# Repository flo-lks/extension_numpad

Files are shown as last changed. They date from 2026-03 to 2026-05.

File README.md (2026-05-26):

# Extension Numpad
4x4 numpad to connect to your PC if you don't have one. The rotary encoder can be used to control the PC volume.
Future additions could include a way to switch between different keymaps to use it as a real macro pad.

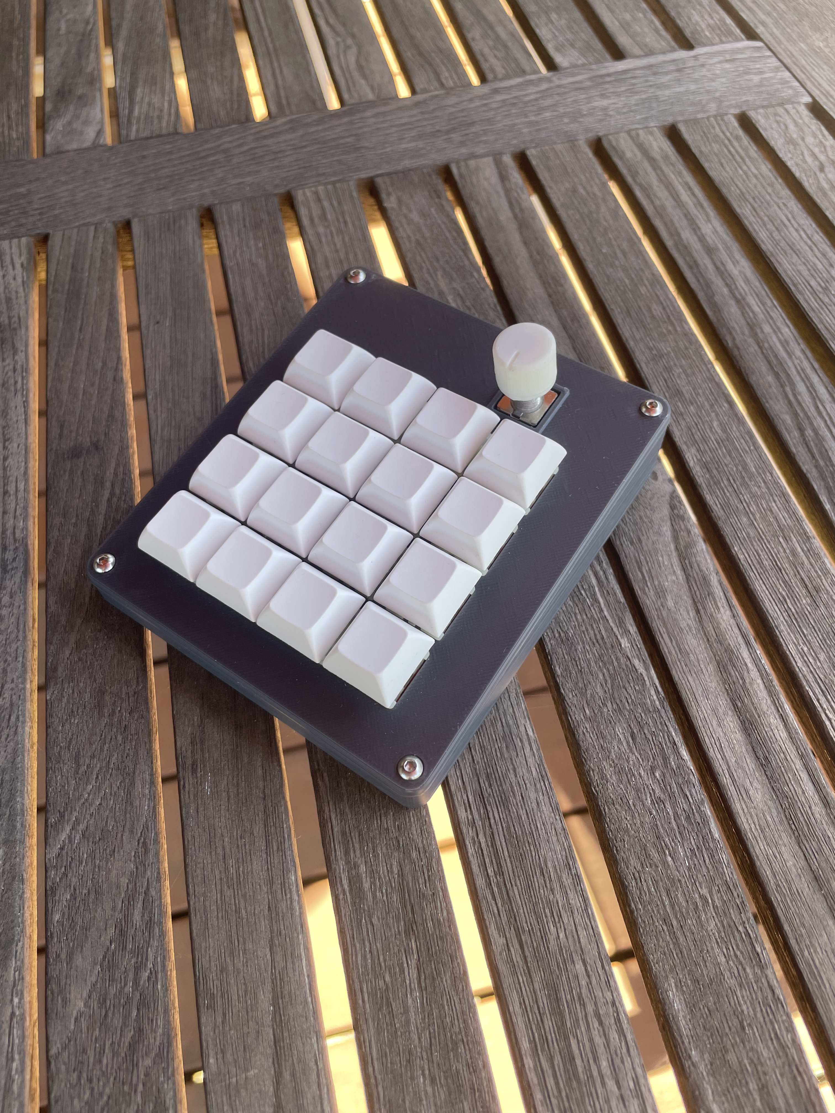
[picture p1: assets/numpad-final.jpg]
final picture of numpad


[demo](https://youtu.be/KasFj6y4_b8)

## PCB
### Schematic
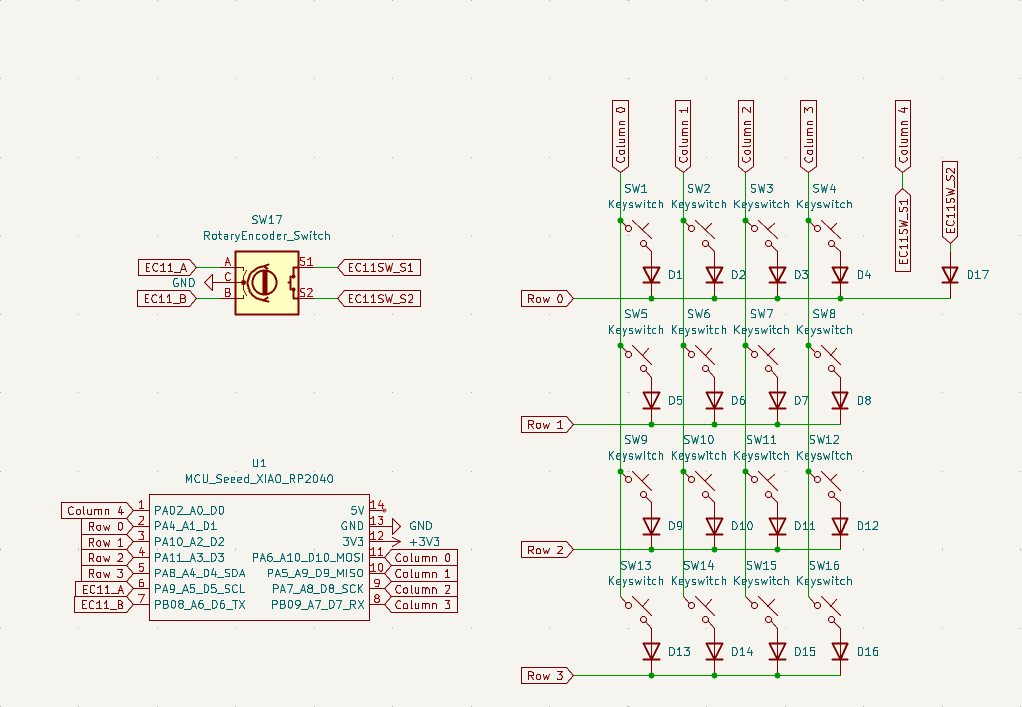
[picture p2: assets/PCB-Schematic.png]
PCB Schematic


### PCB Layout
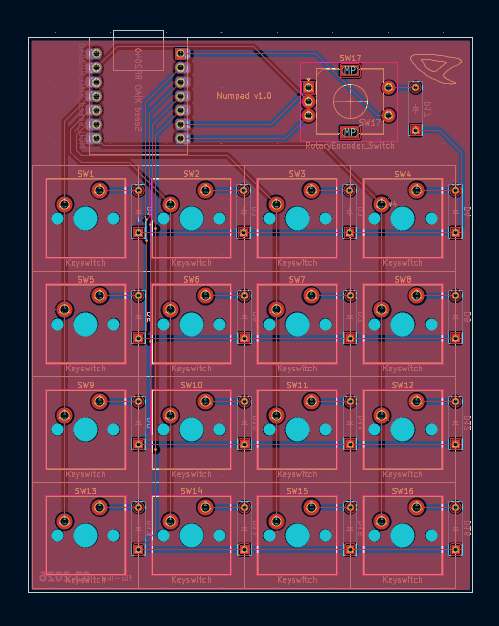
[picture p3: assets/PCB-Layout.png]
PCB Layout


### PCB 3D Model
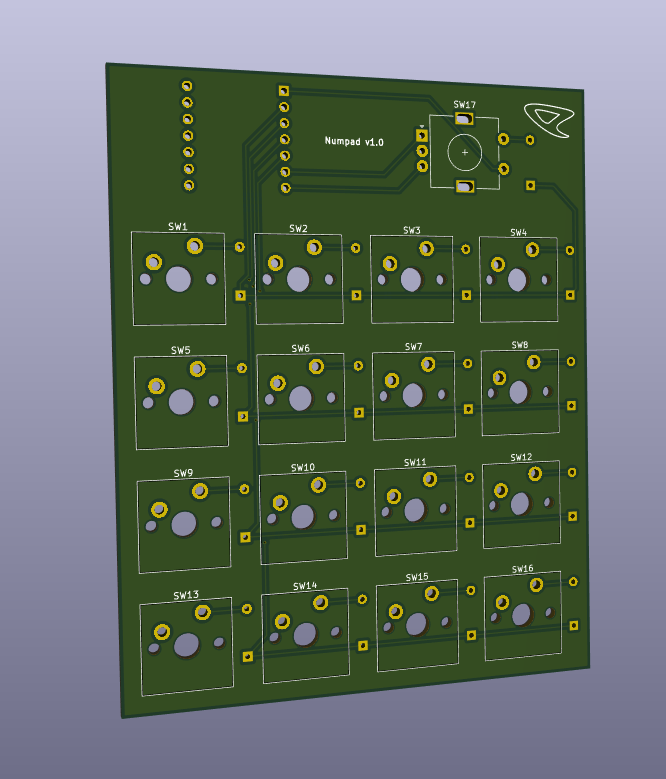
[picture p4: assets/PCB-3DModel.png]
PCB 3D model


## Case
I use a sandwich-mount case design, which consists of a base and a top part. It is angled at 7 degrees for a more comfortable typing experience. The switches clip into the top plate, which is screwed to the base with the help of the heatset inserts.
Here are the OnShape Links to all parts: [Base](https://cad.onshape.com/documents/cdbf6aaf84bb518f5fc41afd/w/d72aa09dfed84ea584997cdd/e/9ded30b820c111a83a06e4c5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), [Top](https://cad.onshape.com/documents/c205197f0eaaebc37cb0e7a9/w/398f6db9231d82ebe460adb4/e/7adaa80a929649ca5ef38242), [Rotarydial](https://cad.onshape.com/documents/0cc47eeeedf213fb4d3bd97f/w/859b01936aa7040036e683de/e/ecc9304a4732aee6efb41bf1), [Assembled](https://cad.onshape.com/documents/a27341ff84a250cd76250f05/w/721d63d8f915e883e9c7e543/e/c5b1b98a970bf75277e2f763)

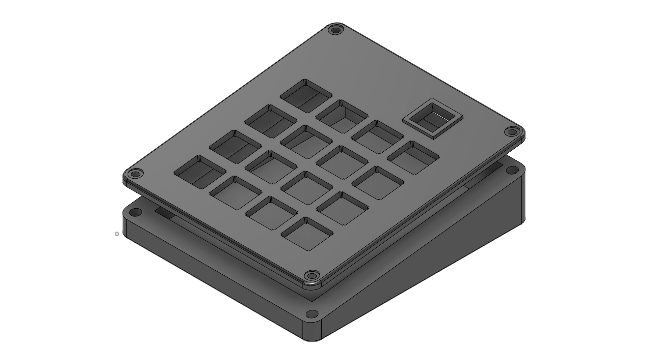
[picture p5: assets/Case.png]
Render of the case


## Firmware
This numpad uses the [QMK](https://qmk.fm/) firmware, with a basic numpad layout.

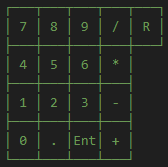
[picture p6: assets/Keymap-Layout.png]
Keymap-Layout


## BOM
| Qty | Part |
|-----|---|
| 1 | 3D Printed Case (1x Base, 1x Top) |
| 1 | EC11 (Switch) Rotary Encoder |
| 1 | PCB |
| 1 | Rotary Encoder Knob |
| 1 | Seeed Studio XIAO RP2040 |
| 2 | M3x16mm screws |
| 2 | M3x8mm screws |
| 4 | M3x5mx4mm heatset inserts |
| 16  | Diodes (1N4148) |
| 16  | MX Keycaps |
| 16  | MX Style Switches |

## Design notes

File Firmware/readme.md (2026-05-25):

# flo_4x4_numpad

Render of the numpad

4x4 numpad to connect to your PC if you don't have one. The rotary encoder can be used to control the PC volume.

* Keyboard Maintainer: [flo-lks](https://github.com/flo-lks)
* Hardware Supported: Seeed Studio RP2040
* Hardware Availability: [Seeed Studio RP2040](https://wiki.seeedstudio.com/XIAO-RP2040/)

Make example for this keyboard (QMK MSYS and after setting up your build environment):

    qmk compile -kb flo_4x4_numpad -km default

Flashing example for this keyboard (QMK MSYS):

    qmk flash -kb flo_4x4_numpad -km default

    or drag the compiled .uf2 file to the RP2040 when it's in bootloader mode

See the [build environment setup](https://docs.qmk.fm/#/getting_started_build_tools) and the [make instructions](https://docs.qmk.fm/#/getting_started_make_guide) for more information. Brand new to QMK? Start with our [Complete Newbs Guide](https://docs.qmk.fm/#/newbs).

## Bootloader

Enter the bootloader in 2 ways:

* **Bootmagic reset**: Hold down the key at (0,0) in the matrix or the 7 key and plug in the keyboard
* **Physical bootloader button**: Hold the Bootloader button (bottom right corner, labeled "B") on the PCB

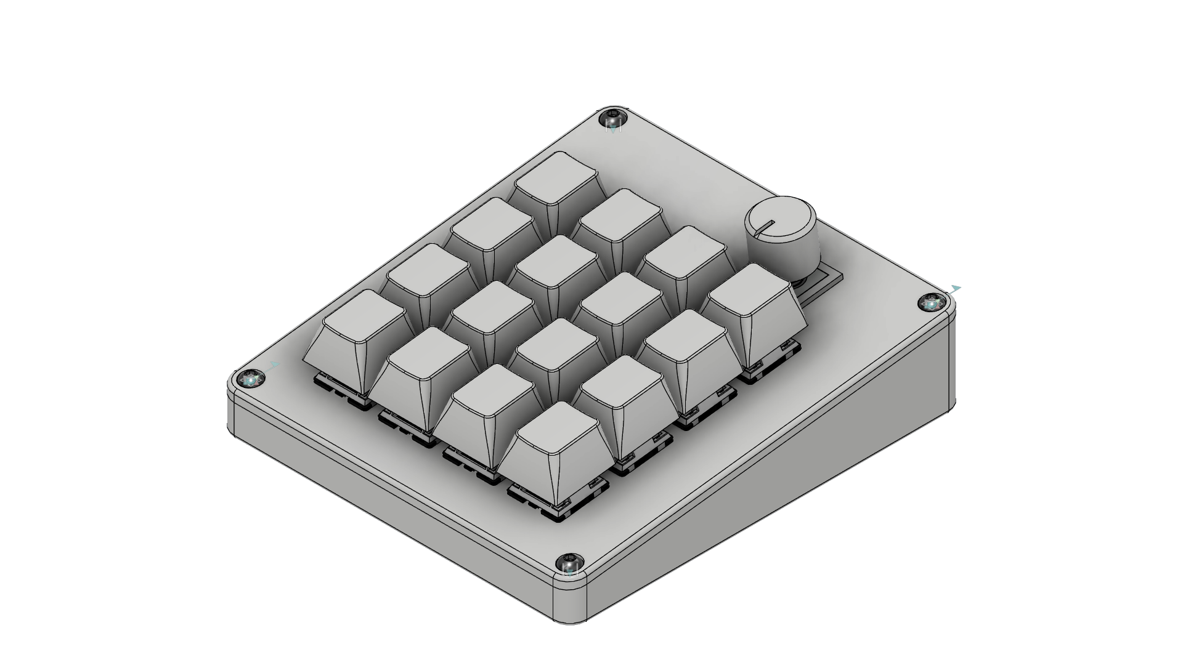
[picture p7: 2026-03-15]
assets/numpad_full.png

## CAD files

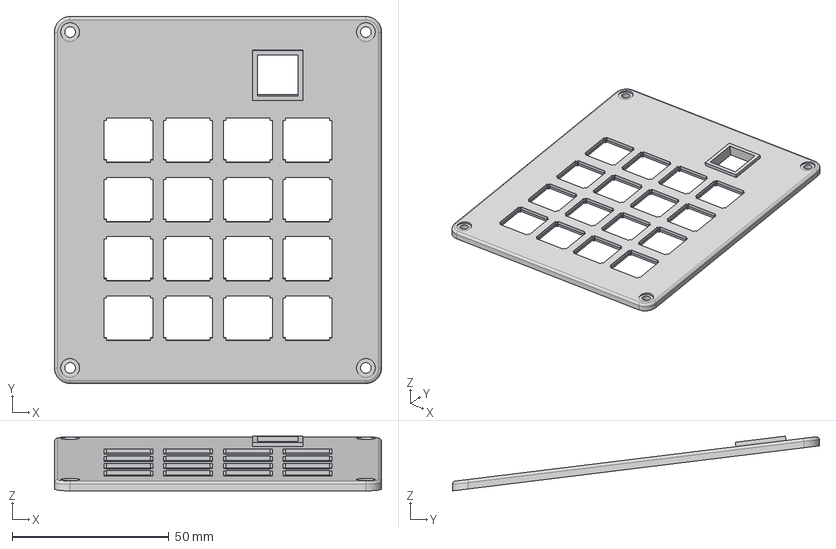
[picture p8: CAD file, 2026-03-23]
CAD/Individual Parts/Case_Top.step
104.3 x 117.0 x 17.5 mm

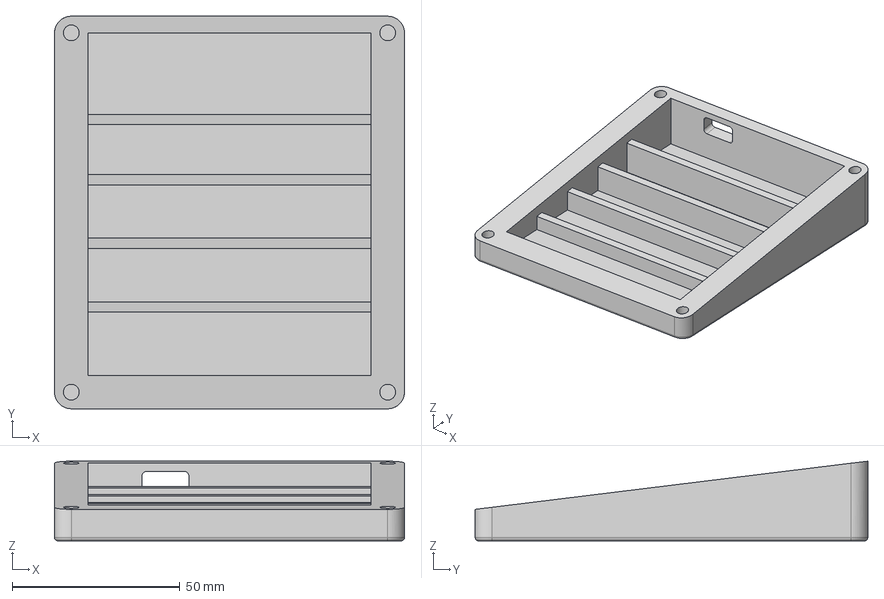
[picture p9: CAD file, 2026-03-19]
CAD/Individual Parts/Case_Base.step
104.3 x 117.0 x 23.8 mm

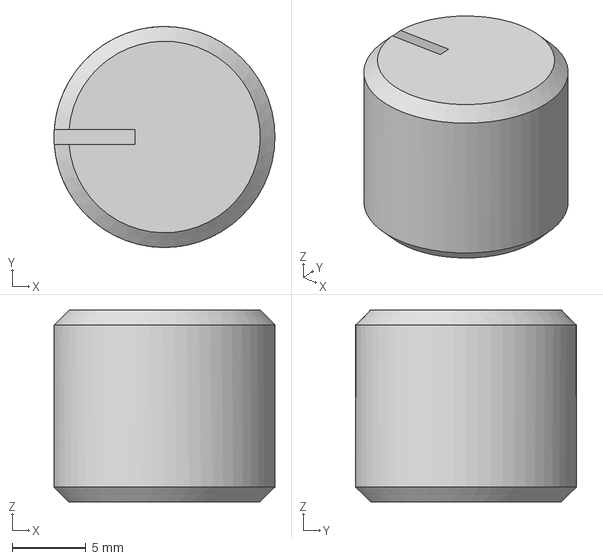
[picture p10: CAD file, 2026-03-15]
CAD/Individual Parts/rotarydial.step
15.0 x 15.0 x 13.0 mm

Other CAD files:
CAD/Individual Parts/Case_Base.f3d
CAD/Individual Parts/Case_Top.f3d
CAD/Individual Parts/rotarydial.f3d
CAD/Numpad_assembled.f3z
production/Case_Base.stl
production/Case_Top.stl
production/rotarydial.stl

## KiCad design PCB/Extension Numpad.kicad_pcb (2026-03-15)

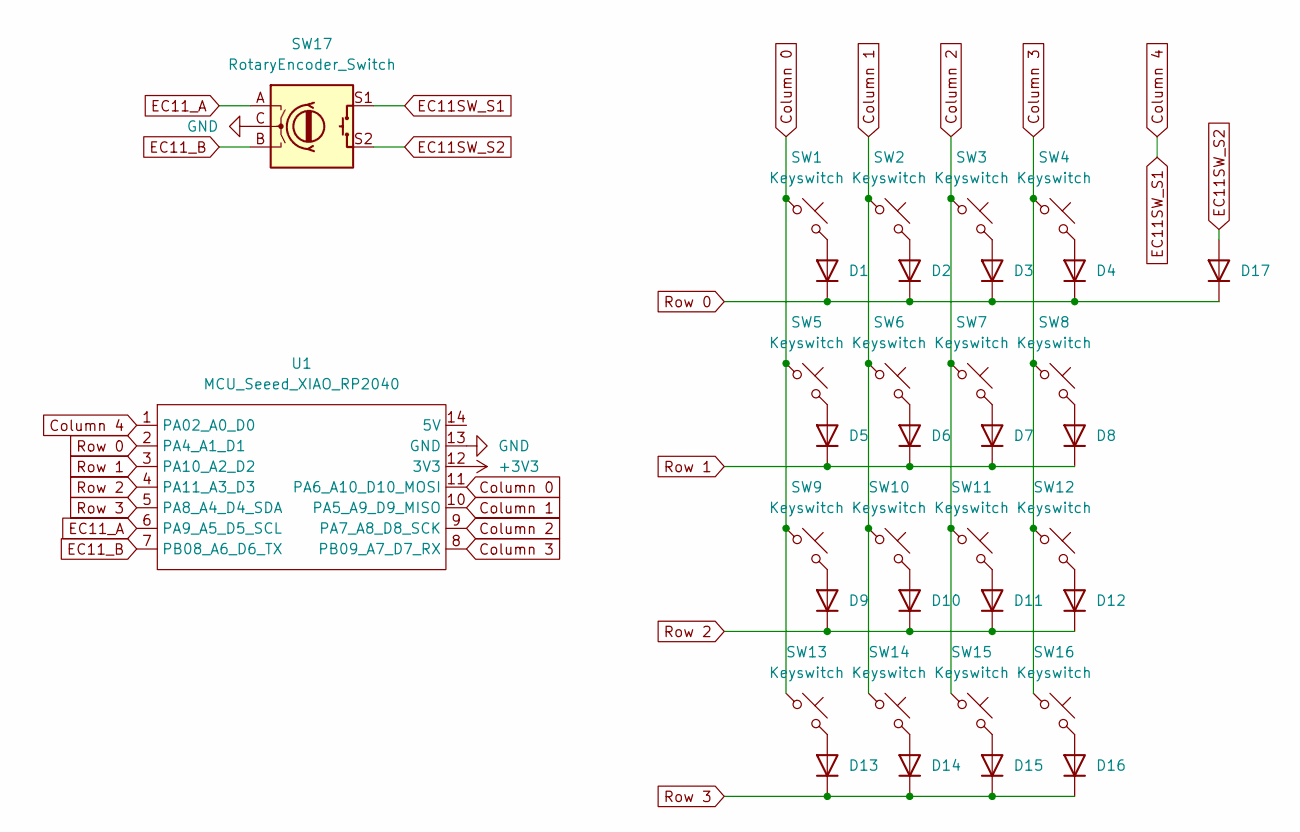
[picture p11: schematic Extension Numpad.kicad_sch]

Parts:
D1, D2, D3, D4, D5, D6, D7, D8, D9, D10, D11, D12, D13, D14, D15, D16, D17: 1N4148; Diode_DO-35
SW1, SW2, SW3, SW4, SW5, SW6, SW7, SW8, SW9, SW10, SW11, SW12, SW13, SW14, SW15, SW16: Keyswitch; MX_PCB_1.00u
SW17: RotaryEncoder_Switch; RotaryEncoder_Alps_EC11E-Switch_Vertical_H20mm
U1: MCU_Seeed_XIAO_RP2040; Seeed_XIAO_RP2040

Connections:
+3V3: U1.12 (3V3)
Column 0: SW1.1, SW5.1, SW9.1, SW13.1, U1.11 (PA6_A10_D10_MOSI)
Column 1: SW2.1, SW6.1, SW10.1, SW14.1, U1.10 (PA5_A9_D9_MISO)
Column 2: SW3.1, SW7.1, SW11.1, SW15.1, U1.9 (PA7_A8_D8_SCK)
Column 3: SW4.1, SW8.1, SW12.1, SW16.1, U1.8 (PB09_A7_D7_RX)
Column 4: SW17.S1, U1.1 (PA02_A0_D0)
EC11SW_S2: D17.2 (A), SW17.S2
EC11_A: SW17.A, U1.6 (PA9_A5_D5_SCL)
EC11_B: SW17.B, U1.7 (PB08_A6_D6_TX)
GND: SW17.C, U1.13 (GND)
unnamed: D1.2 (A), SW1.2
unnamed: D2.2 (A), SW2.2
unnamed: D3.2 (A), SW3.2
unnamed: D4.2 (A), SW4.2
unnamed: D5.2 (A), SW5.2
unnamed: D6.2 (A), SW6.2
unnamed: D7.2 (A), SW7.2
unnamed: D8.2 (A), SW8.2
unnamed: D9.2 (A), SW9.2
unnamed: D10.2 (A), SW10.2
unnamed: D11.2 (A), SW11.2
unnamed: D12.2 (A), SW12.2
unnamed: D13.2 (A), SW13.2
unnamed: D14.2 (A), SW14.2
unnamed: D15.2 (A), SW15.2
unnamed: D16.2 (A), SW16.2
Row 0: D1.1 (K), D2.1 (K), D3.1 (K), D4.1 (K), D17.1 (K), U1.2 (PA4_A1_D1)
Row 1: D5.1 (K), D6.1 (K), D7.1 (K), D8.1 (K), U1.3 (PA10_A2_D2)
Row 2: D9.1 (K), D10.1 (K), D11.1 (K), D12.1 (K), U1.4 (PA11_A3_D3)
Row 3: D13.1 (K), D14.1 (K), D15.1 (K), D16.1 (K), U1.5 (PA8_A4_D4_SDA)

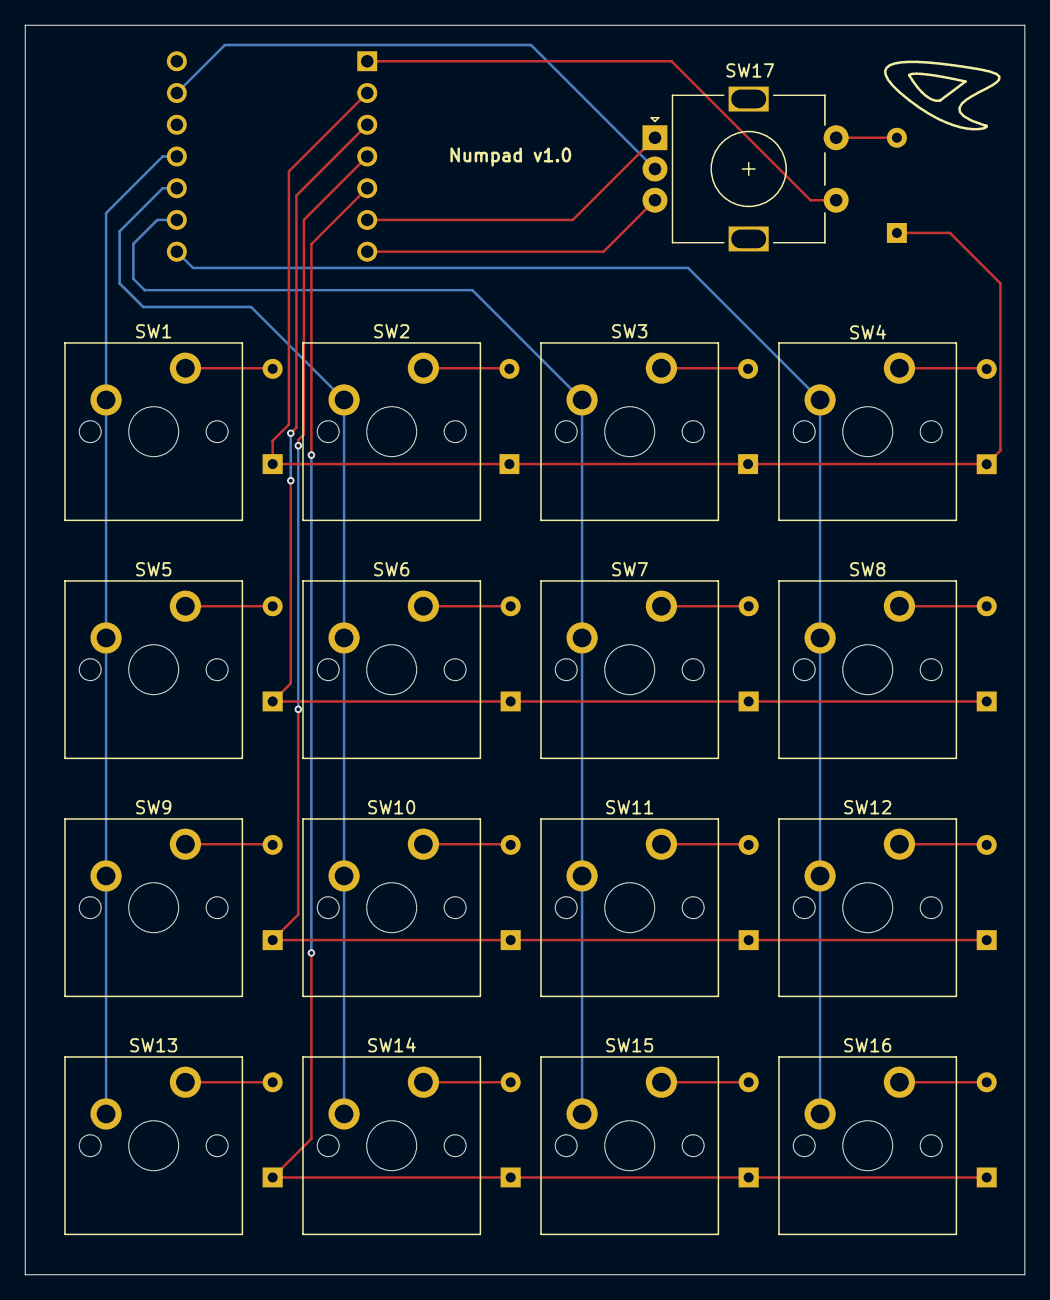
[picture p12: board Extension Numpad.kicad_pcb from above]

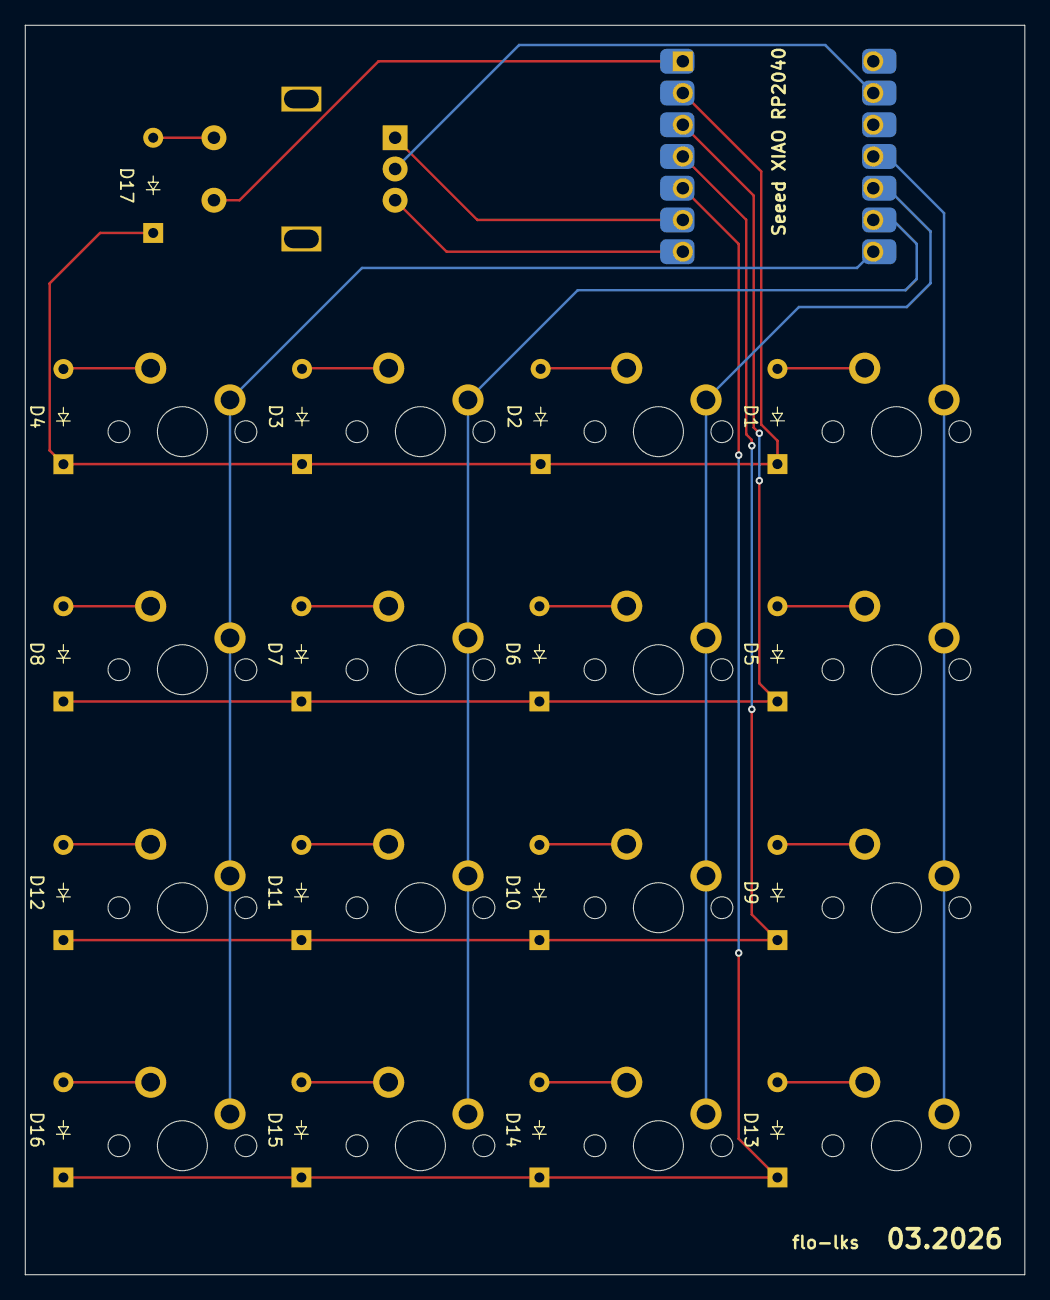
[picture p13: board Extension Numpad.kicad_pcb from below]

Board: 2 copper layers, 80.0 x 100.0 mm, 35 parts (18 on the bottom side), 29 nets.

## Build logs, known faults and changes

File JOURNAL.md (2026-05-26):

---
title: "extension_numpad"
author: "flo-lks"
description: "4x4 extension numpad"
created_at: "06.03.2026"
---

# 06.03.2026: Getting started
## What did I do?
I began with setting up KiCad and importing necessary libraries (HackClub "care package", ScottoKeebs', Rotary-Encoder librarie).
With the help of some YouTube videos (mainly from Joe Scott), I learned about KiCad and started with the project.
After a bit of trial and error, I got the Schematics down and made my way to the PCB Editor. At first this was a bit tricky, but I got the base layout done fairly quickly.
I then wanted to add the rotary encoder, but when I wanted to update my PCB Editor it didn't recognize the connections from EC11SW_S1 and EC11SW_S2. After about half an hour, I realized that
the connections were not recognized because of a wrong footprint I assigned to the encoder.
Lastly, I connected everything and played around a little with the design of the board.

## Images
Schematic
PCB
3D model

**Time spent: 4h - 5h**

# 08.03.2026: Case Design
## What did I do?
I decided to design my case as a sandwich-mount type, and I also wanted it to be slightly angled. The hardest part was, once again, getting comfortable with Fusion 360. I have used Blender before, but in my opinion, Fusion is completely different, and I found it quite hard to get into. However, nothing a few YouTube tutorials couldn't fix.
I started by modeling the plate with the help of the online designer linked in the [resources](https://blueprint.hackclub.com/hackpad/resources). I added a hole for the rotary encoder and extended it to fit the entire PCB. The base was the hardest part since I had to figure out a few things, like how to add an angle, but I eventually managed to do it.
A few things are still missing, such as a cutout for the USB-C port and the angled sides I still want to add.

## Images
Case-Model

**Time spent: 5h - 6h**

# 10.03.2026: Case Design
## What did I do?
I finished the 3D model of the case. I added holes for the screws and the heatset insterts as well as a cutout for the USB-C port. I also realized that the rotary encoder wasn't going to fit in the hole I intended for it, so I had to make a new cutout for it.
Most challenging were definitely the screw holes. I found it very hard to get the measurements down correctly, especially because of the angled top part. I made a lot of little mistakes, which caused a lot of back and forth.

## Images
Case-HomePos
Case-Back
Numpad-Assembled

**Time spent: 4h**

# 10.03.2026 - 17.03.2026
## What did I do?
I didn't have a lot of time to write a journal entry every time I worked on the project, and most of the time I did only small changes.
I added a few things to the case, like a dial for the rotary encoder or the keycaps, to make a nice render. But mainly I worked on the firmware. I use QMK because it was said that it is the easiest for beginners. I still found it hard to really get into the whole QMK system. But with the help of a few YouTube tutorials, I at least managed to set up the files correctly, and the implementation of the switches was easy. The rotary encoder, on the other hand, was a problem. I couldn't find anything that explained well how to implement it. That's when I turned to AI, and with the help of Gemini, I think I figured it out, but I am still not quite sure how it works (at least it complied right, so surely it will work).
With that done, I submitted the project today and am now waiting for the review.

## Images
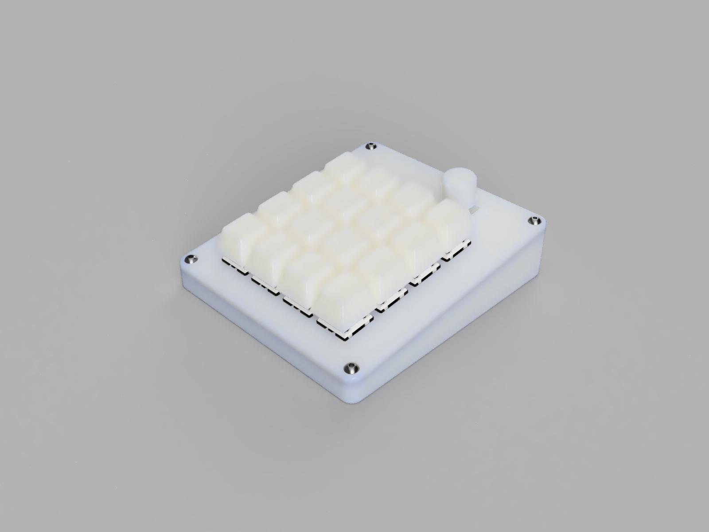
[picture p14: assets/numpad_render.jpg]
Numpad-Render


**Time spent: 10h**

# 23.05.2026: Soldered the PCB and tested Firmware
## What did I do?
Today the rest of the parts I have been waiting for finally arrived, and I could start assembling.

### **Soldering**

First I soldered on the diodes, then the PR2024, the rotary encoder, and lastly the switches.
I have soldered a few times before, so it went pretty smoothly. After the first few pins were soldered, the rest was done in no time.

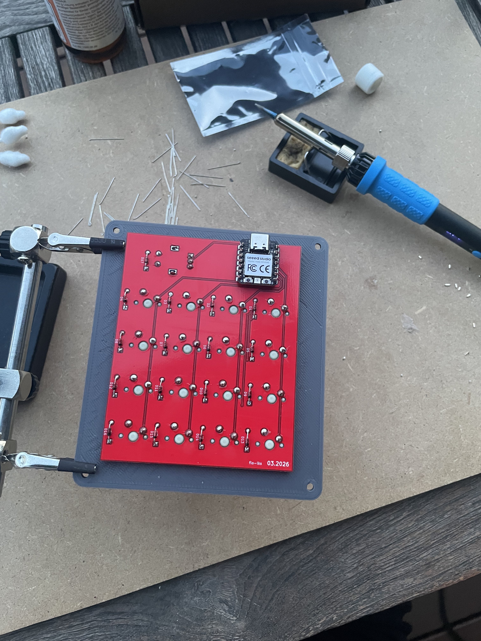
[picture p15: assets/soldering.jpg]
PCB-soldering


The only major problem I encountered was the cutout for the USB-C connector. Somehow the cutout in the case was too high for the USB connector.

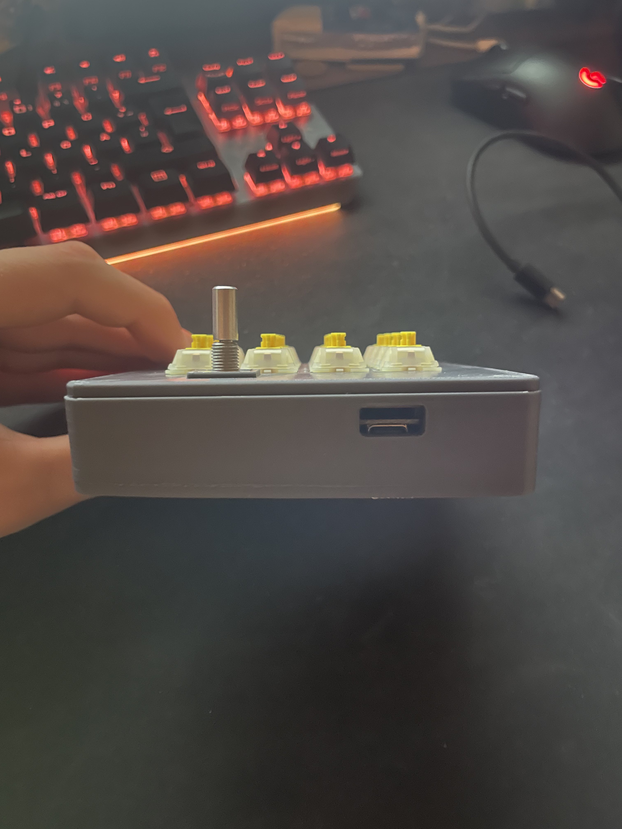
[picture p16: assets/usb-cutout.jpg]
usb-cutout


### **Firmware test**
After I finished the soldering, I tried flashing my firmware.

First I had to figure out how to flash it but found help on the seeedstudio wiki. After I put it into bootloader mode and copied the .uf2 file into the folder, I tried typing and opened a keyboard tester website.

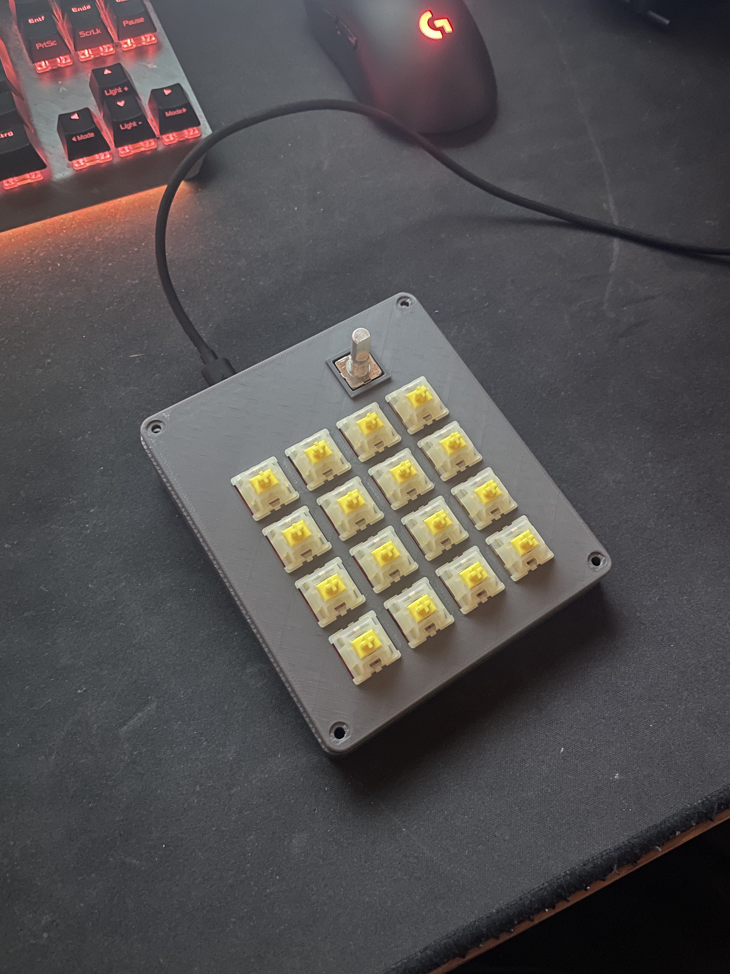
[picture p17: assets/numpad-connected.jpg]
Numpad-Connected


To my surprise, all keys worked, but not quite how they should. At least the four keys for the operations (/, *, -, +), the enter key, and the mute function of the encoder worked, but all other keys were doing something else.

For example:

- Key 0: insert
- Key 2: arrow down
- Key 3: PgDwn

I will look into the firmware again and fix it, and if it all works, I will go on to the case and fix the USB cutout as well as insert the heatset inserts.

**Time spent: 5h**

# 26.05.2026: Firmware and Case Fixes
## What did I do?

### **Case**
To fix the problem with the USB-C port, I sanded down the cutout so a cable now fits in without issues.
After that, I installed heatset inserts and cut two screws down to 8 mm so they fit into the bottom two mounting holes.

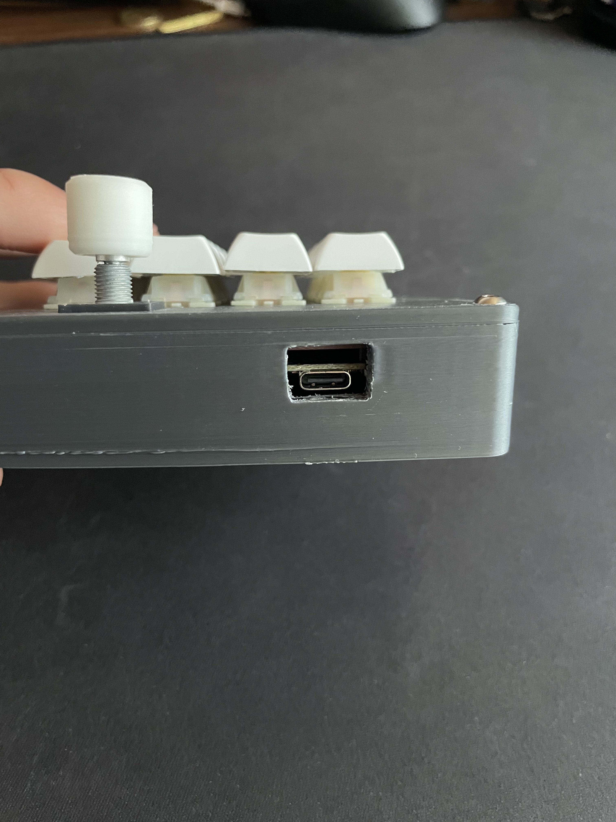
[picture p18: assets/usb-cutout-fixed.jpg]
USB-cutout-fixed


### **Firmware**
**Numlock Toggle:**
A numpad uses different key mappings than the normal number row, since the keys also serve as arrow keys and other functions. The solution was to add a way to activate and deactivate Numlock.

I tried several approaches, including a key combination, but that caused unwanted inputs while toggling Numlock. Instead, I implemented a long-press detection on the mute key: if the mute key is held for longer than 300 ms, Numlock toggles.

**Volume Control:**
The issue with volume control was caused by incorrect pin configurations in keyboard.json. The encoder pins A and B were assigned incorrectly. After correcting the pin assignments, the volume control now works as expected.

**Now my intended functions for a Numpad all work, and it is ready to be shipped**
final picture of numpad

**Time spent: 3h**

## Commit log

2026-03-08 Designing the case in Fusion 360
2026-03-11 Add entry for case design progress on 10.03.2026
2026-03-15 update format of BOM to table
2026-03-17 add: rotary encoder logic to firmware
2026-03-19 add: PCB supports and f3d files
    [Case_Base.f3d, Case_Base.step, Case_Top.f3d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]
2026-03-23 fix: hole dimensions and alignment
    [Case_Top.f3d, Case_Top.step]
2026-03-23 fix: OnShape links for top and assembled
2026-03-31 Add: .stl files
    [Case_Base.stl, Case_Top.stl, rotarydial.stl]
2026-05-25 fix: keymap and encoder pin assignments
